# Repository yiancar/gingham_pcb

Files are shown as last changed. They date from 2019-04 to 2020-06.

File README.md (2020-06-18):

Gingham
================

tartan

The ANSI/ISO keyboard kit made using ONLY through hole components and inspired by the [Plaid](https://github.com/hsgw/plaid).

Atmega328p with VUSB on [QMK firmware](https://github.com/qmk/qmk_firmware).

To alter the pcb use KiCAD V5.0 or newer as it already contains most of the libraries. The additional libraries are provided.

License
===========

This project is licensed under the [Creative Commons Attribution-NonCommercial 4.0 International License](https://creativecommons.org/licenses/by-nc/4.0/).

If you have remixed, adapted or build upon this work and wish to remove the non-commercial clause for your own project please contact me at https://www.yiancar-designs.com. Your request is more than likely to be granted. The non-commercial part of the license is intended to avoid direct copies of the work to be sold for commercial gain by third parties.



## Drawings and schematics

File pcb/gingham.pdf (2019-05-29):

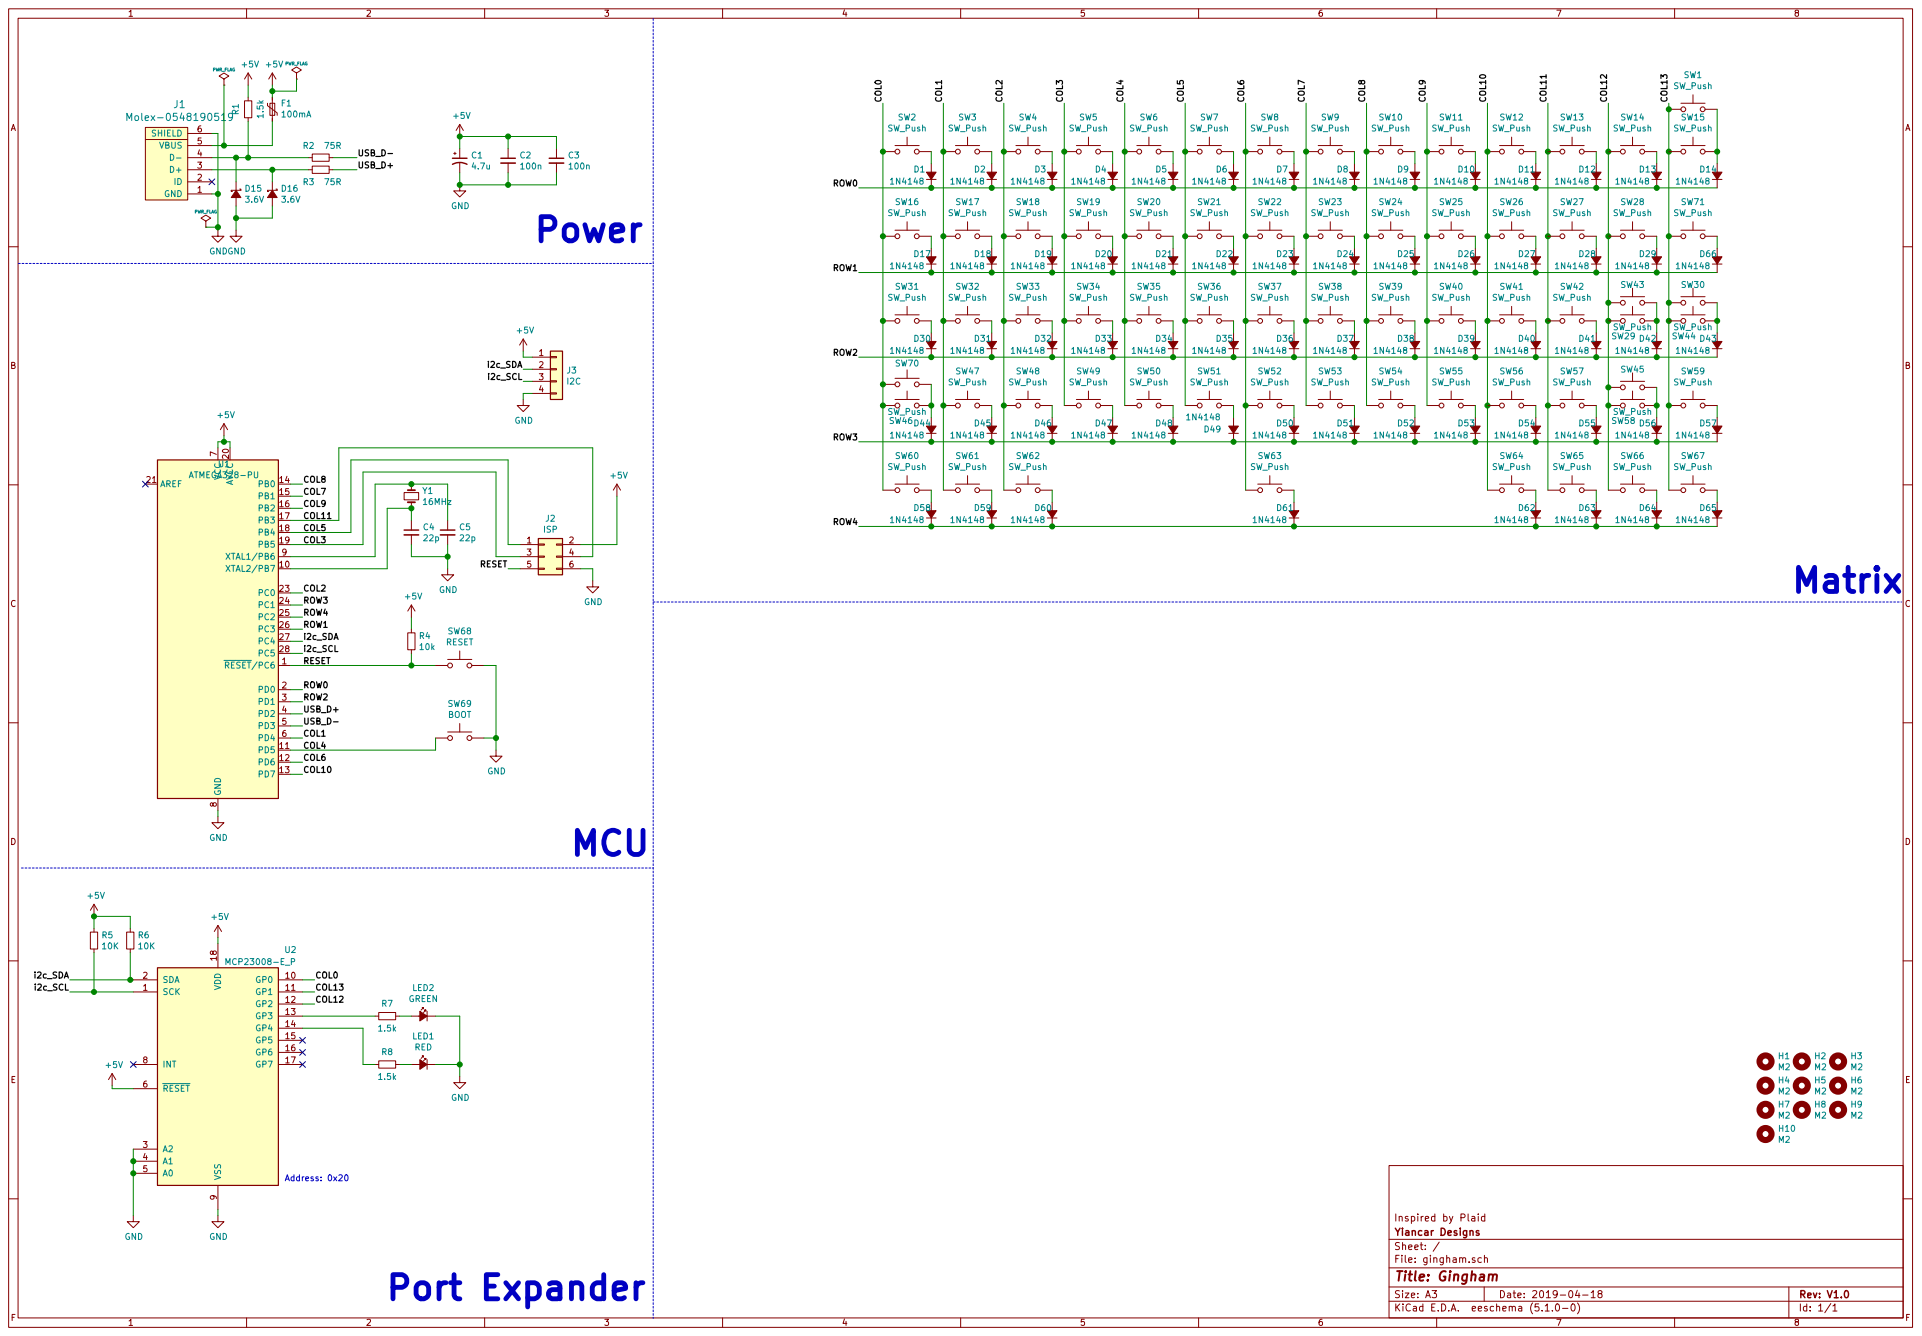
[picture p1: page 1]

Inspired by Plaid
File: gingham.sch Sheet: / Yiancar Designs

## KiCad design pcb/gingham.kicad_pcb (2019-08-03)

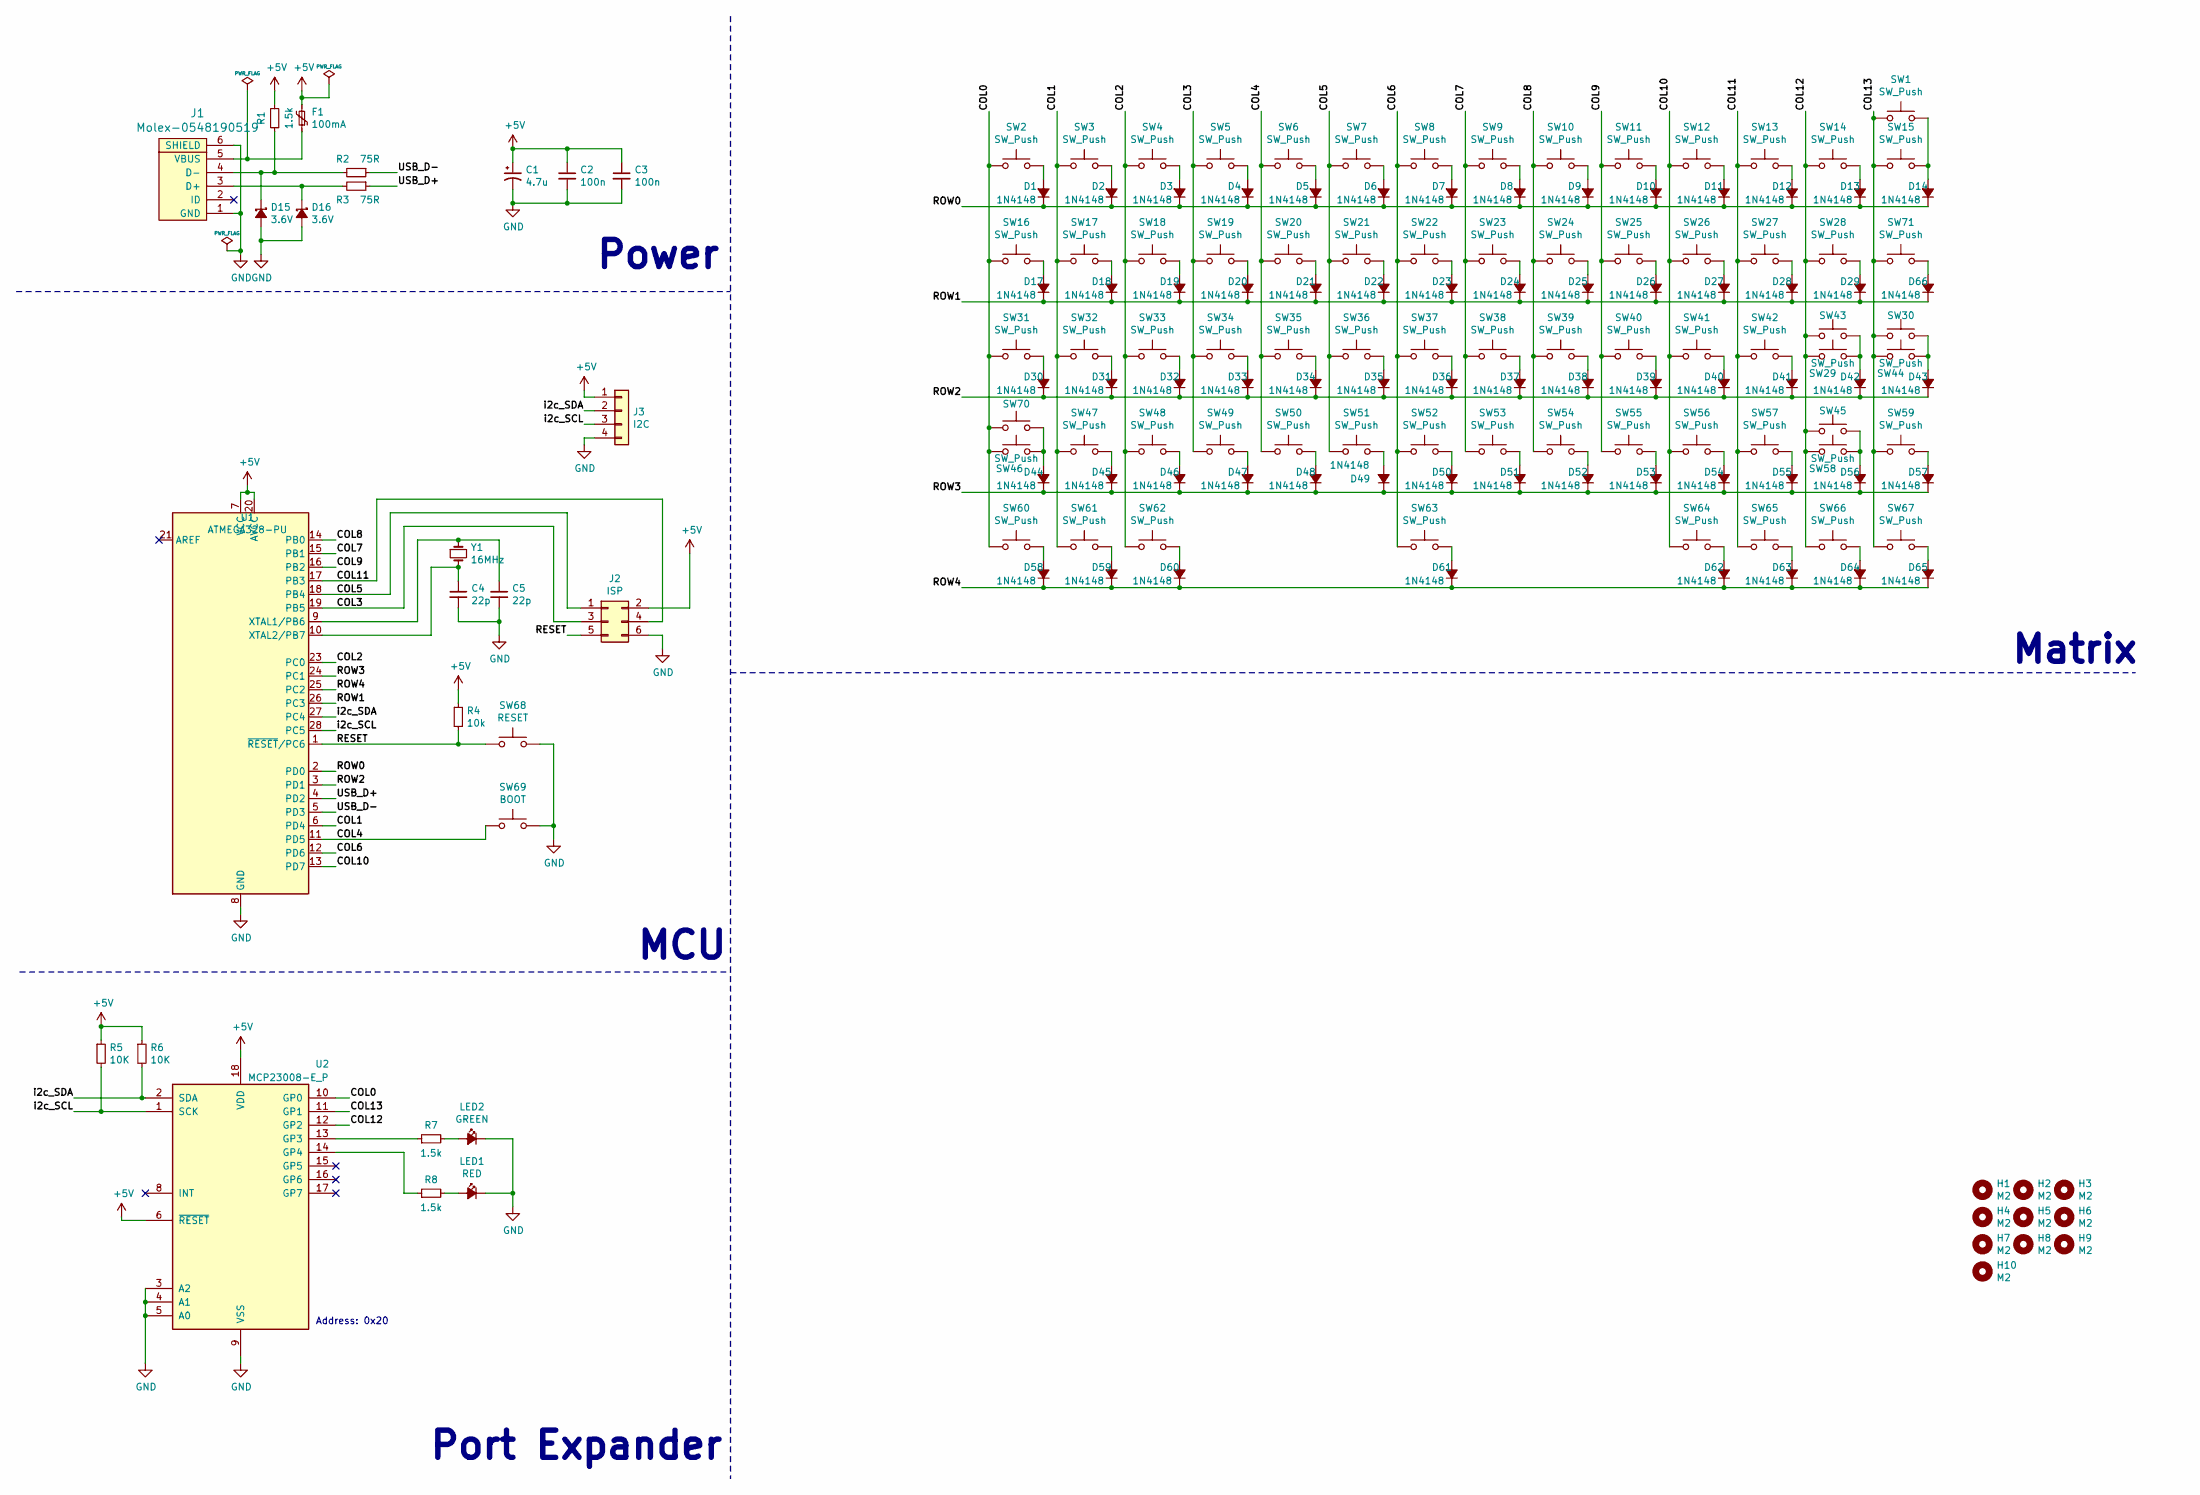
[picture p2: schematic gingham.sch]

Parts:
C1: 4.7u; CP_Radial_D4.0mm_P1.50mm
C2, C3: 100n; C_Disc_D4.3mm_W1.9mm_P5.00mm
C4, C5: 22p; C_Disc_D3.0mm_W1.6mm_P2.50mm
D1, D2, D3, D4, D5, D6, D7, D8, D9, D10, D11, D12, D13, D14, D17, D18, D19, D20, D21, D22, D23, D24, D25, D26, D27, D28, D29, D30, D31, D32, D33, D34, D35, D36, D37, D38, D39, D40, D41, D42, D43, D44, D45, D46, D47, D48, D49, D50, D51, D52, D53, D54, D55, D56, D57, D58, D59, D60, D61, D62, D63, D64, D65, D66: 1N4148; D_DO-35_SOD27_P7.62mm_Horizontal
D15, D16: 3.6V; D_DO-35_SOD27_P7.62mm_Horizontal
F1: 100mA; C_Disc_D5.0mm_W2.5mm_P5.00mm
H1, H2, H3, H4, H5, H6, H7, H8, H9, H10: M2; MountingHole_2.2mm_M2_DIN965_Pad
J1: Molex-0548190519
J2: ISP; PinHeader_2x03_P2.54mm_Vertical
J3: I2C; PinHeader_1x04_P2.54mm_Vertical
LED1: RED; LED_D3.0mm_Clear
LED2: GREEN; LED_D3.0mm_Clear
R1, R7, R8: 1.5k; R_Axial_DIN0204_L3.6mm_D1.6mm_P5.08mm_Horizontal
R2, R3: 75R; R_Axial_DIN0204_L3.6mm_D1.6mm_P5.08mm_Horizontal
R4: 10k; R_Axial_DIN0204_L3.6mm_D1.6mm_P5.08mm_Horizontal
R5, R6: 10K; R_Axial_DIN0204_L3.6mm_D1.6mm_P5.08mm_Horizontal
SW1: SW_Push; MX-2U-NoLED
SW2, SW3, SW4, SW5, SW6, SW7, SW8, SW9, SW10, SW11, SW12, SW13, SW14, SW15, SW17, SW18, SW19, SW20, SW21, SW22, SW23, SW24, SW25, SW26, SW27, SW28, SW29, SW32, SW33, SW34, SW35, SW36, SW37, SW38, SW39, SW40, SW41, SW42, SW47, SW48, SW49, SW50, SW51, SW52, SW53, SW54, SW55, SW56, SW57, SW59, SW71: SW_Push; MX-1U-NoLED
SW16, SW43: SW_Push; MX-1.5U-NoLED
SW30: SW_Push; MX-ISO-ReversedStabilizers
SW31, SW45: SW_Push; MX-1.75U-NoLED
SW44, SW46: SW_Push; MX-2.25U-NoLED
SW58: SW_Push; MX-2.75U-NoLED
SW60, SW61, SW62, SW64, SW65, SW66, SW67, SW70: SW_Push; MX-1.25U-NoLED
SW63: SW_Push; MX-6.25U-ReversedStabilizers-NoLED
SW68: RESET; SW_PUSH_6mm
SW69: BOOT; SW_PUSH_6mm
U1: ATMEGA328-PU; DIP-28_W7.62mm
U2: MCP23008-E_P; DIP-18_W7.62mm
Y1: 16MHz; Crystal_HC49-4H_Vertical

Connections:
+5V: C1.1, C2.1, C3.1, F1.2, J2.2, J3.1, R1.2, R4.1, R5.1, R6.1, U1.7 (VCC), U1.20 (AVCC), U2.6 (~RESET~), U2.18 (VDD)
/COL0: SW2.2, SW16.2, SW31.2, SW46.2, SW60.2, SW70.2, U2.10 (GP0)
/COL1: SW3.2, SW17.2, SW32.2, SW47.2, SW61.2, U1.6 (PD4)
/COL2: SW4.2, SW18.2, SW33.2, SW48.2, SW62.2, U1.23 (PC0)
/COL3: J2.3, SW5.2, SW19.2, SW34.2, SW49.2, U1.19 (PB5)
/COL4: SW6.2, SW20.2, SW35.2, SW50.2, SW69.1, U1.11 (PD5)
/COL5: J2.1, SW7.2, SW21.2, SW36.2, SW51.2, U1.18 (PB4)
/COL6: SW8.2, SW22.2, SW37.2, SW52.2, SW63.2, U1.12 (PD6)
/COL7: SW9.2, SW23.2, SW38.2, SW53.2, U1.15 (PB1)
/COL8: SW10.2, SW24.2, SW39.2, SW54.2, U1.14 (PB0)
/COL9: SW11.2, SW25.2, SW40.2, SW55.2, U1.16 (PB2)
/COL10: SW12.2, SW26.2, SW41.2, SW56.2, SW64.2, U1.13 (PD7)
/COL11: J2.4, SW13.2, SW27.2, SW42.2, SW57.2, SW65.2, U1.17 (PB3)
/COL12: SW14.2, SW28.2, SW29.2, SW43.2, SW45.2, SW58.2, SW66.2, U2.12 (GP2)
/COL13: SW1.2, SW15.2, SW30.2, SW44.2, SW59.2, SW67.2, SW71.2, U2.11 (GP1)
/RESET: J2.5, R4.2, SW68.1, U1.1 (~RESET~/PC6)
/ROW0: D1.1 (K), D2.1 (K), D3.1 (K), D4.1 (K), D5.1 (K), D6.1 (K), D7.1 (K), D8.1 (K), D9.1 (K), D10.1 (K), D11.1 (K), D12.1 (K), D13.1 (K), D14.1 (K), U1.2 (PD0)
/ROW1: D17.1 (K), D18.1 (K), D19.1 (K), D20.1 (K), D21.1 (K), D22.1 (K), D23.1 (K), D24.1 (K), D25.1 (K), D26.1 (K), D27.1 (K), D28.1 (K), D29.1 (K), D66.1 (K), U1.26 (PC3)
/ROW2: D30.1 (K), D31.1 (K), D32.1 (K), D33.1 (K), D34.1 (K), D35.1 (K), D36.1 (K), D37.1 (K), D38.1 (K), D39.1 (K), D40.1 (K), D41.1 (K), D42.1 (K), D43.1 (K), U1.3 (PD1)
/ROW3: D44.1 (K), D45.1 (K), D46.1 (K), D47.1 (K), D48.1 (K), D49.1 (K), D50.1 (K), D51.1 (K), D52.1 (K), D53.1 (K), D54.1 (K), D55.1 (K), D56.1 (K), D57.1 (K), U1.24 (PC1)
/ROW4: D58.1 (K), D59.1 (K), D60.1 (K), D61.1 (K), D62.1 (K), D63.1 (K), D64.1 (K), D65.1 (K), U1.25 (PC2)
/USB_D+: R3.1, U1.4 (PD2)
/USB_D-: R2.1, U1.5 (PD3)
/i2c_SCL: J3.3, R5.2, U1.28 (PC5), U2.1 (SCK)
/i2c_SDA: J3.2, R6.2, U1.27 (PC4), U2.2 (SDA)
GND: C1.2, C2.2, C3.2, C4.2, C5.2, D15.2 (A), D16.2 (A), J1.1 (GND), J1.6 (SHIELD), J2.6, J3.4, LED1.1 (K), LED2.1 (K), SW68.2, SW69.2, U1.8 (GND), U1.22 (GND), U2.3 (A2), U2.4 (A1), U2.5 (A0), U2.9 (VSS)
unnamed: C4.1, U1.10 (XTAL2/PB7), Y1.2
unnamed: C5.1, U1.9 (XTAL1/PB6), Y1.1
unnamed: D1.2 (A), SW2.1
unnamed: D2.2 (A), SW3.1
unnamed: D3.2 (A), SW4.1
unnamed: D4.2 (A), SW5.1
unnamed: D5.2 (A), SW6.1
unnamed: D6.2 (A), SW7.1
unnamed: D7.2 (A), SW8.1
unnamed: D8.2 (A), SW9.1
unnamed: D9.2 (A), SW10.1
unnamed: D10.2 (A), SW11.1
unnamed: D11.2 (A), SW12.1
unnamed: D12.2 (A), SW13.1
unnamed: D13.2 (A), SW14.1
unnamed: D14.2 (A), SW1.1, SW15.1
unnamed: D15.1 (K), J1.4 (D-), R1.1, R2.2
unnamed: D16.1 (K), J1.3 (D+), R3.2
unnamed: D17.2 (A), SW16.1
unnamed: D18.2 (A), SW17.1
unnamed: D19.2 (A), SW18.1
unnamed: D20.2 (A), SW19.1
unnamed: D21.2 (A), SW20.1
unnamed: D22.2 (A), SW21.1
unnamed: D23.2 (A), SW22.1
unnamed: D24.2 (A), SW23.1
unnamed: D25.2 (A), SW24.1
unnamed: D26.2 (A), SW25.1
unnamed: D27.2 (A), SW26.1
unnamed: D28.2 (A), SW27.1
unnamed: D29.2 (A), SW28.1
unnamed: D30.2 (A), SW31.1
unnamed: D31.2 (A), SW32.1
unnamed: D32.2 (A), SW33.1
unnamed: D33.2 (A), SW34.1
unnamed: D34.2 (A), SW35.1
unnamed: D35.2 (A), SW36.1
unnamed: D36.2 (A), SW37.1
unnamed: D37.2 (A), SW38.1
unnamed: D38.2 (A), SW39.1
unnamed: D39.2 (A), SW40.1
unnamed: D40.2 (A), SW41.1
unnamed: D41.2 (A), SW42.1
unnamed: D42.2 (A), SW29.1, SW43.1
unnamed: D43.2 (A), SW30.1, SW44.1
unnamed: D44.2 (A), SW46.1, SW70.1
unnamed: D45.2 (A), SW47.1
unnamed: D46.2 (A), SW48.1
unnamed: D47.2 (A), SW49.1
unnamed: D48.2 (A), SW50.1
unnamed: D49.2 (A), SW51.1
unnamed: D50.2 (A), SW52.1
unnamed: D51.2 (A), SW53.1
unnamed: D52.2 (A), SW54.1
unnamed: D53.2 (A), SW55.1
unnamed: D54.2 (A), SW56.1
unnamed: D55.2 (A), SW57.1
unnamed: D56.2 (A), SW45.1, SW58.1
unnamed: D57.2 (A), SW59.1
unnamed: D58.2 (A), SW60.1
unnamed: D59.2 (A), SW61.1
unnamed: D60.2 (A), SW62.1
unnamed: D61.2 (A), SW63.1
unnamed: D62.2 (A), SW64.1
unnamed: D63.2 (A), SW65.1
unnamed: D64.2 (A), SW66.1
unnamed: D65.2 (A), SW67.1
unnamed: D66.2 (A), SW71.1
unnamed: F1.1, J1.5 (VBUS)
unnamed: LED1.2 (A), R8.2
unnamed: LED2.2 (A), R7.2
unnamed: R7.1, U2.13 (GP3)
unnamed: R8.1, U2.14 (GP4)

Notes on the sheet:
Power
Matrix
MCU
Port Expander
Address: 0x20

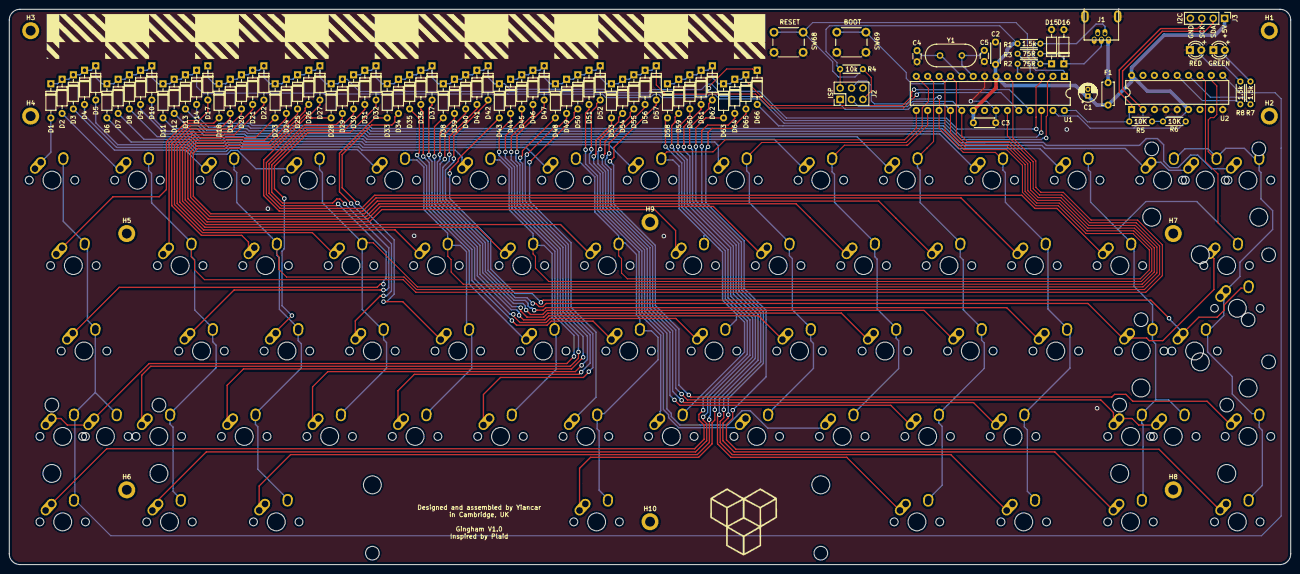
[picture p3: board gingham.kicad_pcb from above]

Board: 2 copper layers, 285.8 x 123.8 mm, 170 parts (0 on the bottom side), 99 nets.

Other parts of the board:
svg2mod: G***; gingham

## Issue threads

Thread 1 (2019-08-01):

Middle screw holes should be moved

BenRoe, 2019-08-01:
Hi,
first thanks for making this beautiful keyboard open source.
I assembled the keyboard and found that the top middle screw, is colliding with a switch.
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

The bottom middle screw is direct under the space stabilizer wire. It works ok.
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

I guess it is enough if you move one screw hole to the arrow position and remove the second.
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

yiancar, 2019-08-01:
Hello Ben, I think the best solution would be to move H9 a bit further up and H10 a bit further down

BenRoe, 2019-08-02:
That seems the easiest solution.
Are you doing it? I could create a PR this weekend.

yiancar, 2019-08-03:
I moved both the mounts. top one went a bit further up to clear the 3 switches.
Bottom one went further down in the spacebar area.

https://github.com/yiancar/gingham_pcb/commit/b1900f6dbd8959f06bac23ca52f8e2e1b224f5ad

BenRoe, 2019-08-03:
Should work.
Thank you for doing it and keep working on new keyboards.

Closed 2019-08-03.

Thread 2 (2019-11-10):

Keyboard on iso abnt2 format

luizcorreia, 2019-11-10:
It's possible make your awesome keyboard work with the abnt2 brazilian format?

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

yiancar, 2020-06-17:
Hello! Sorry Just saw this:)

My design aesthetic calls against making it a "swiss cheese" PCB. As a result I will not be modifying the bottom row to anything other that what it currently is.

Saying this, the design is opensource so you can go ahead and make your own!

Thanks for taking a look !

Closed 2020-06-17.

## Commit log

2019-06-27 Final prep
    [tartan-B_Cu.gbl, tartan-B_Mask.gbs, tartan-B_SilkS.gbo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]
2019-08-03 Relocate middle screwmounts
    [gingham.kicad_pcb, gingham_bottom.kicad_pcb]
